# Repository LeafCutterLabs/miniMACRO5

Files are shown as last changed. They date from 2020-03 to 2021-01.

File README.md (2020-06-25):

# miniMACRO5
QMK-powered macropad based on Arduino Pro Micro. Supports a mix of up to 5 rotary encoders or mechanical switches with optional RGB underglow.
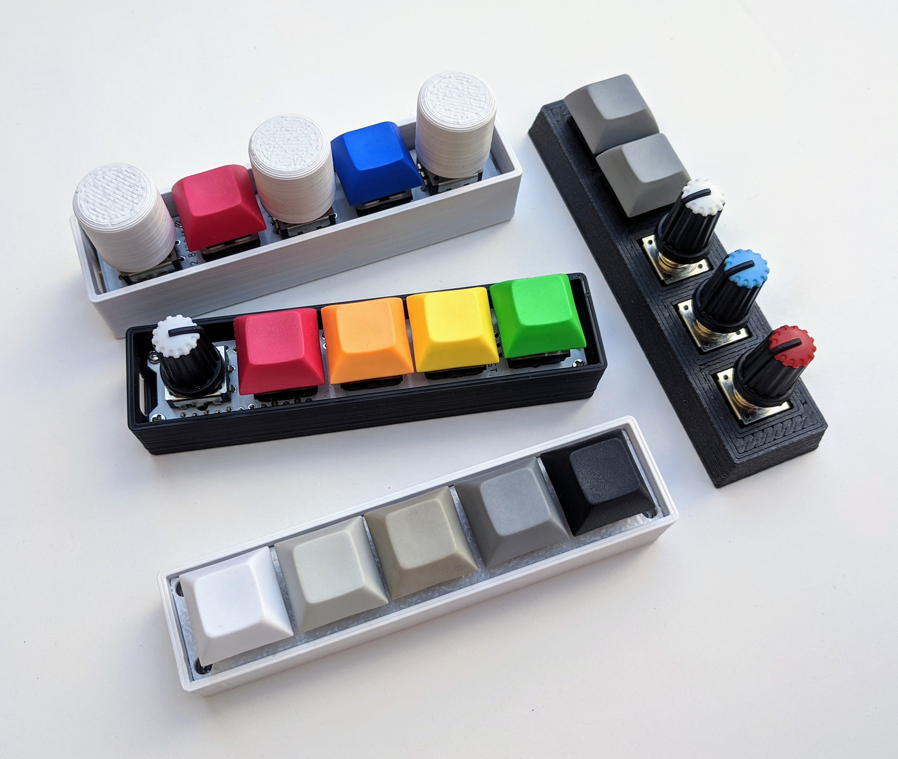
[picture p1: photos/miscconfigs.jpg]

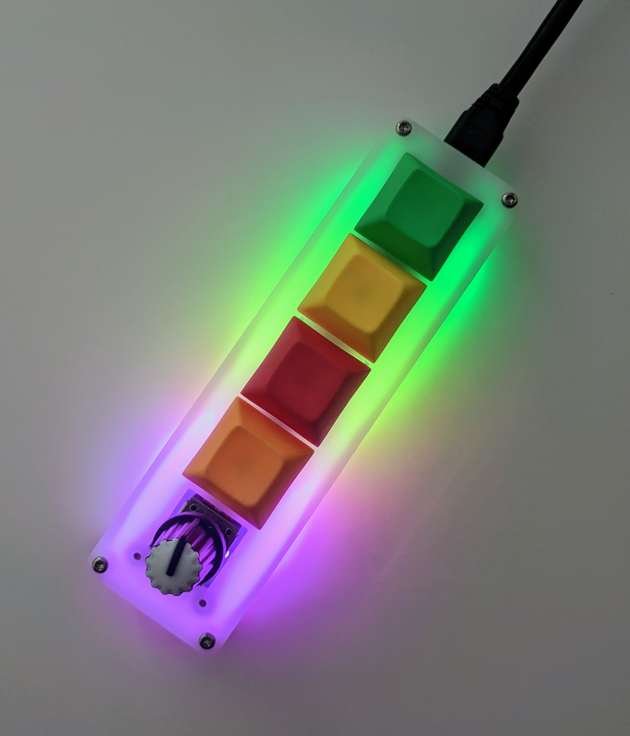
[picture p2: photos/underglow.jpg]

<br>


## Bill of materials (BOM)
### Required components
1. Arduino Pro Micro with headers - available from SparkFun, eBay, Amazon, etc.
2. Rotary encoders - Bourns PEC12R and PEC11R, Alps, and the cheap Chinese versions have been tested. Any quadrature encocder that fits should work. Supports switch encoders.
3. Cherry MX-style switches
4. Keycaps for your chosen switches
5. Case (3d printable STL in `/hardware`)
6. 4x 4mm M2 mounting screws
7. Electrical insulation tape (if you do not have any, at this low voltage and current, regular clear tape will suffice)

### Optional components
1. Reset switch
2. ICSP headers (only required to flash the Arduino if the Caterina bootloader is not present)
3. WS2812 LED strip (for RGB underglow)

## Assembly instructions
[See ASSEMBLY.md](ASSEMBLY.md) for build instructions with photos.

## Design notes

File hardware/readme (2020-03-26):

The v3/v2 stl and laser files will work with v3b boards. The new v3b case includes a top plate.

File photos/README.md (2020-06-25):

Images in this folder show the various stages of the build process.

## Assembly note
The micro USB port is very close to the pins of switch or rotary 0.  A small piece of electrical tape on top of the USB port will ensure there are no shorts.

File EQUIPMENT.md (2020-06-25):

# Equipment
This list of equipment shows what's required to build this project, as well as what is useful.  There's also a [step by step assembly guide](ASSEMBLY.md).

## Required

* Soldering iron (and stand)
* Thin solder
* Solder sucker (for removing solder in the event of mistakes)
* Computer for programming the miniMACRO5 with the QMK firmware
* Micro USB to USB A cable for connecting the miniMACRO5 to the computer

## Optional

* Helping hands (crocodile clips for holding the board, often with a magnifying glass)
* Multimeter for testing connections
* Thin nosed wire cutters / tin snips (for trimming excess header length)

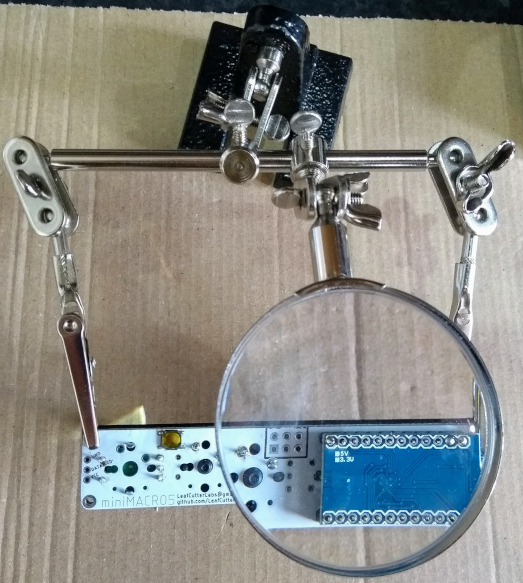
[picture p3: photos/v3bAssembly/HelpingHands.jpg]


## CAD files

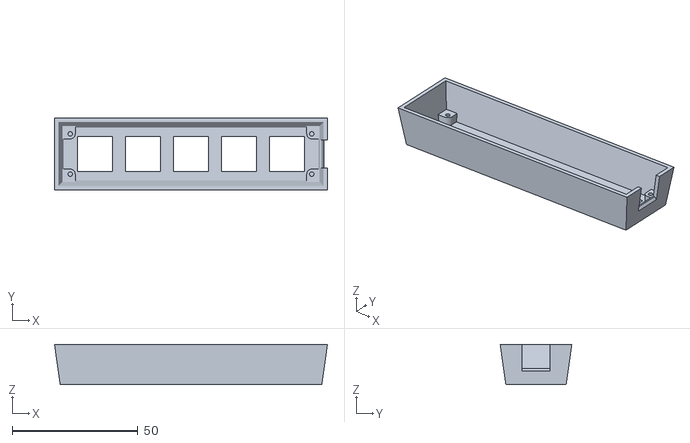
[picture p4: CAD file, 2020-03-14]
hardware/LEDunderglow.stl
108.5 x 28.5 x 16.0

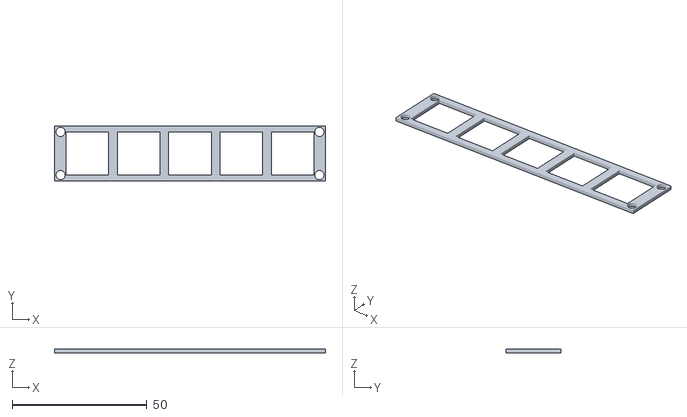
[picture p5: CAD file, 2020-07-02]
hardware/v3b/v3b - drop plate.stl
100.5 x 20.5 x 1.30

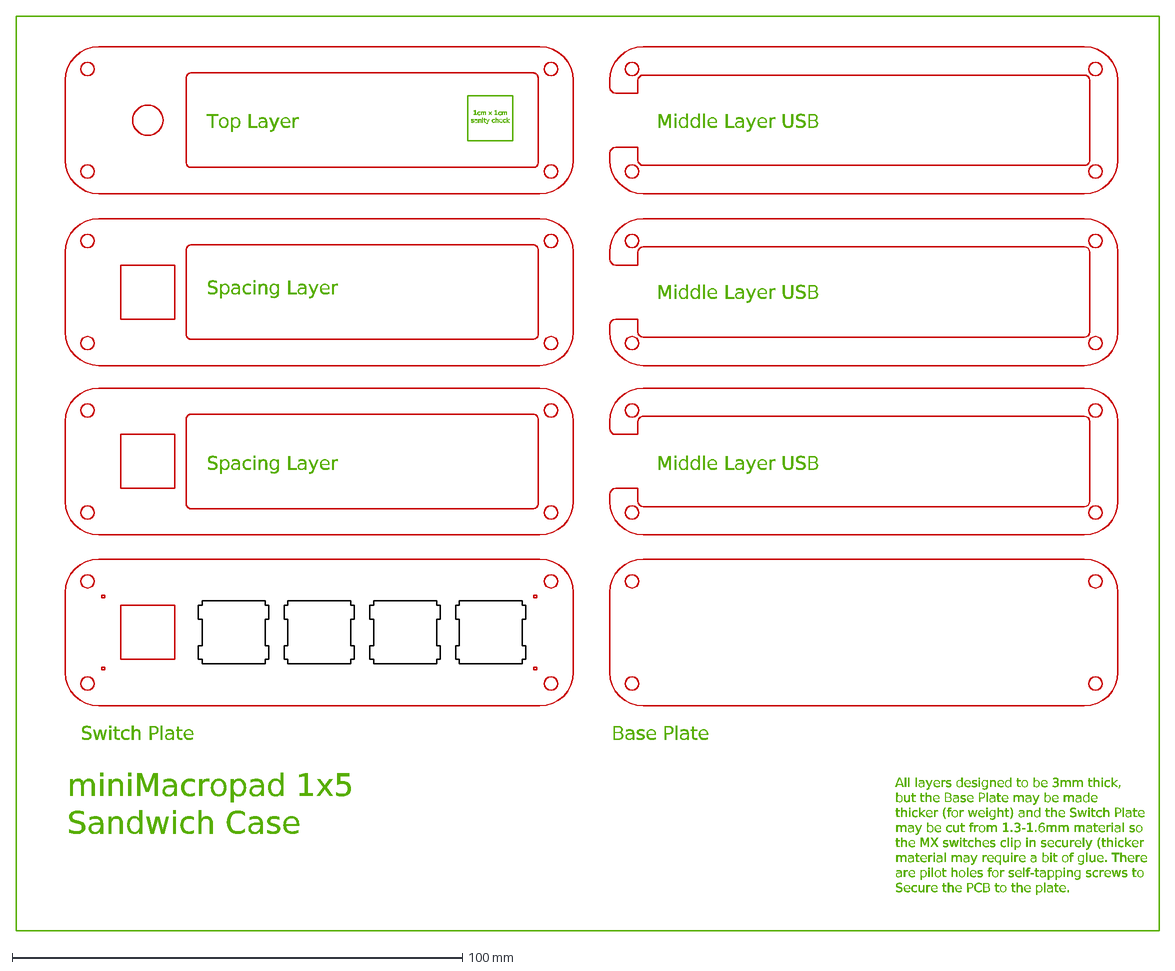
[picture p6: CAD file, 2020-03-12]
hardware/laserCUT.dxf
miniMacropad 1x5 Sandwich Case
All layers designed to be 3mm thick, but the Base Plate may be made thicker (for weight) and the Switch Plate may be cut from 1.3-1.6mm material so the MX switc
1cm x 1cm sanity check
Middle Layer USB
Spacing Layer
Top Layer
Base Plate
Switch Plate

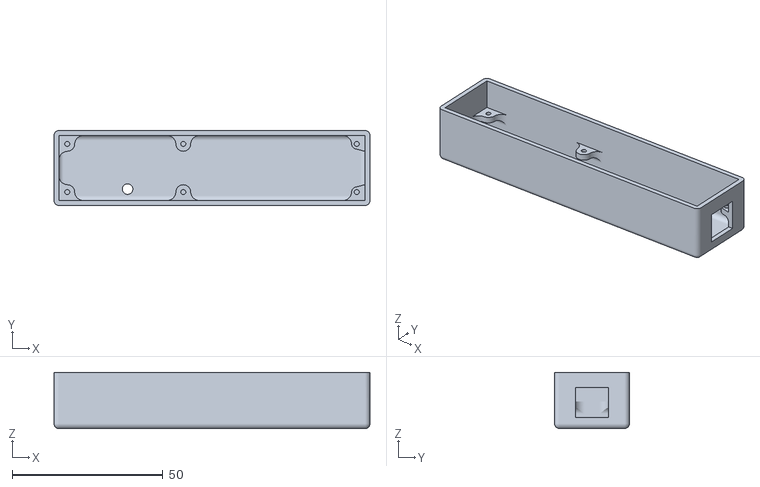
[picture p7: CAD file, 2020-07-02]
hardware/v3b/v3b - drop case.stl
104.8 x 24.8 x 18.6

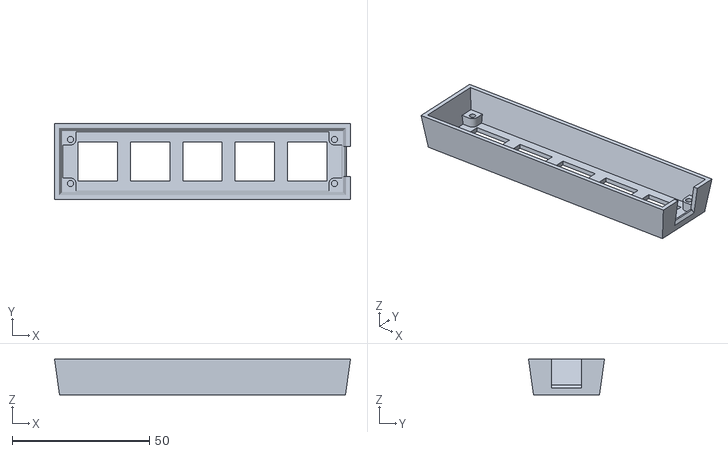
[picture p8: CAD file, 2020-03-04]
hardware/miniMACRO5.stl
107.7 x 27.7 x 13.0

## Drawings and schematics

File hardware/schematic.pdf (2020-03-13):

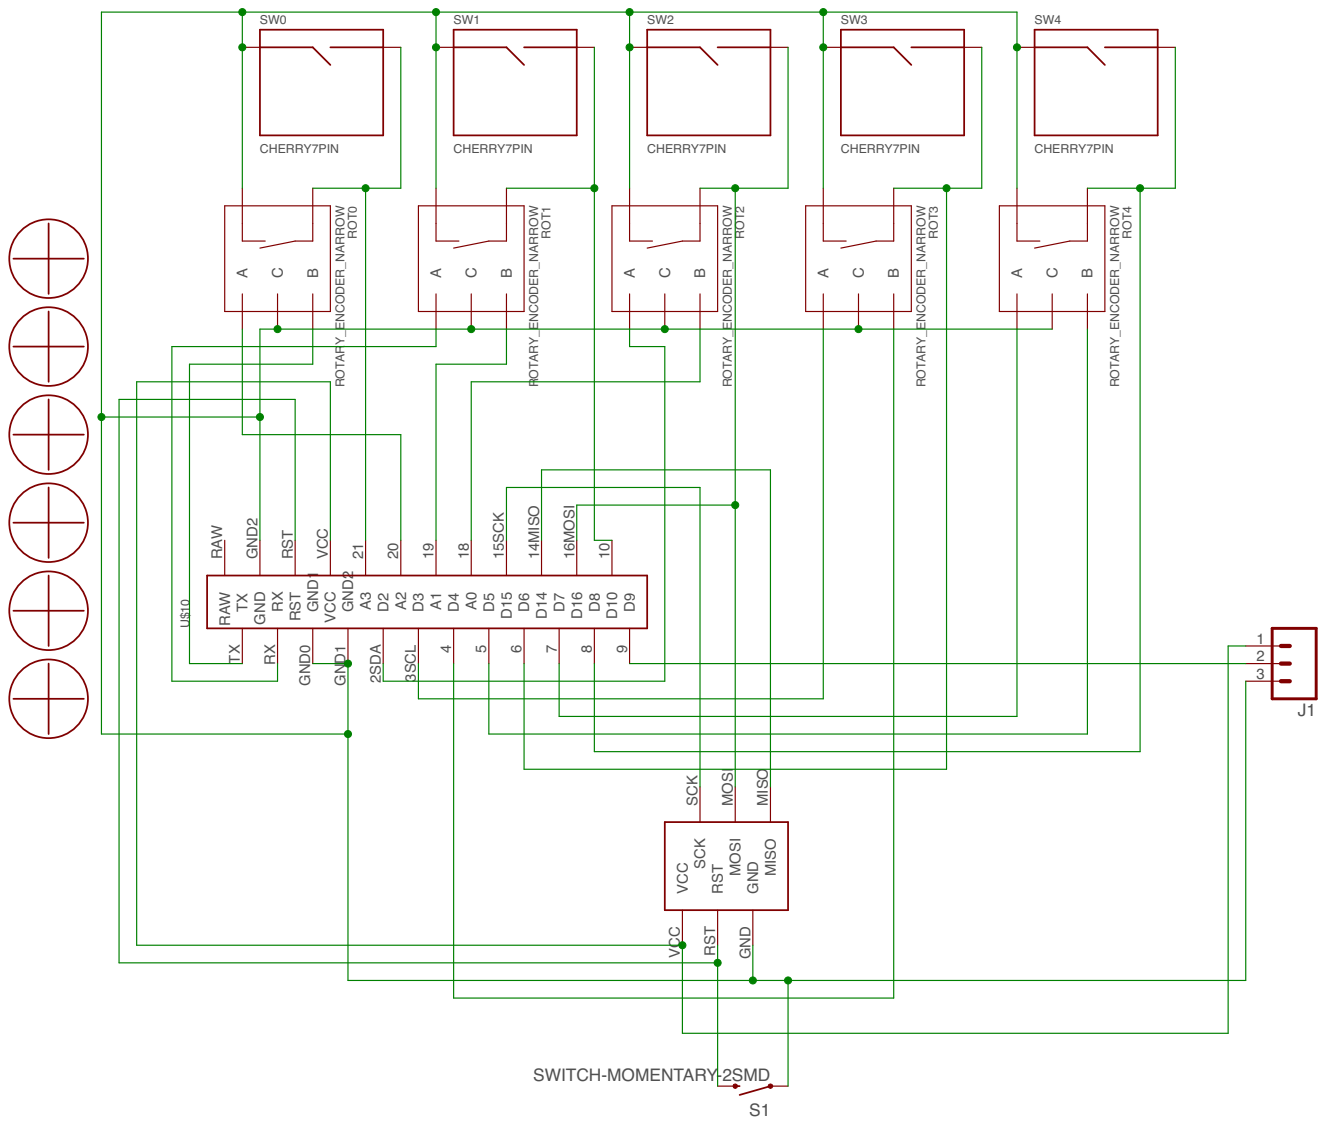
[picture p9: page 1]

RST RST GND GND2 RAW

GND GND MOSI MOSI RST RST VCC

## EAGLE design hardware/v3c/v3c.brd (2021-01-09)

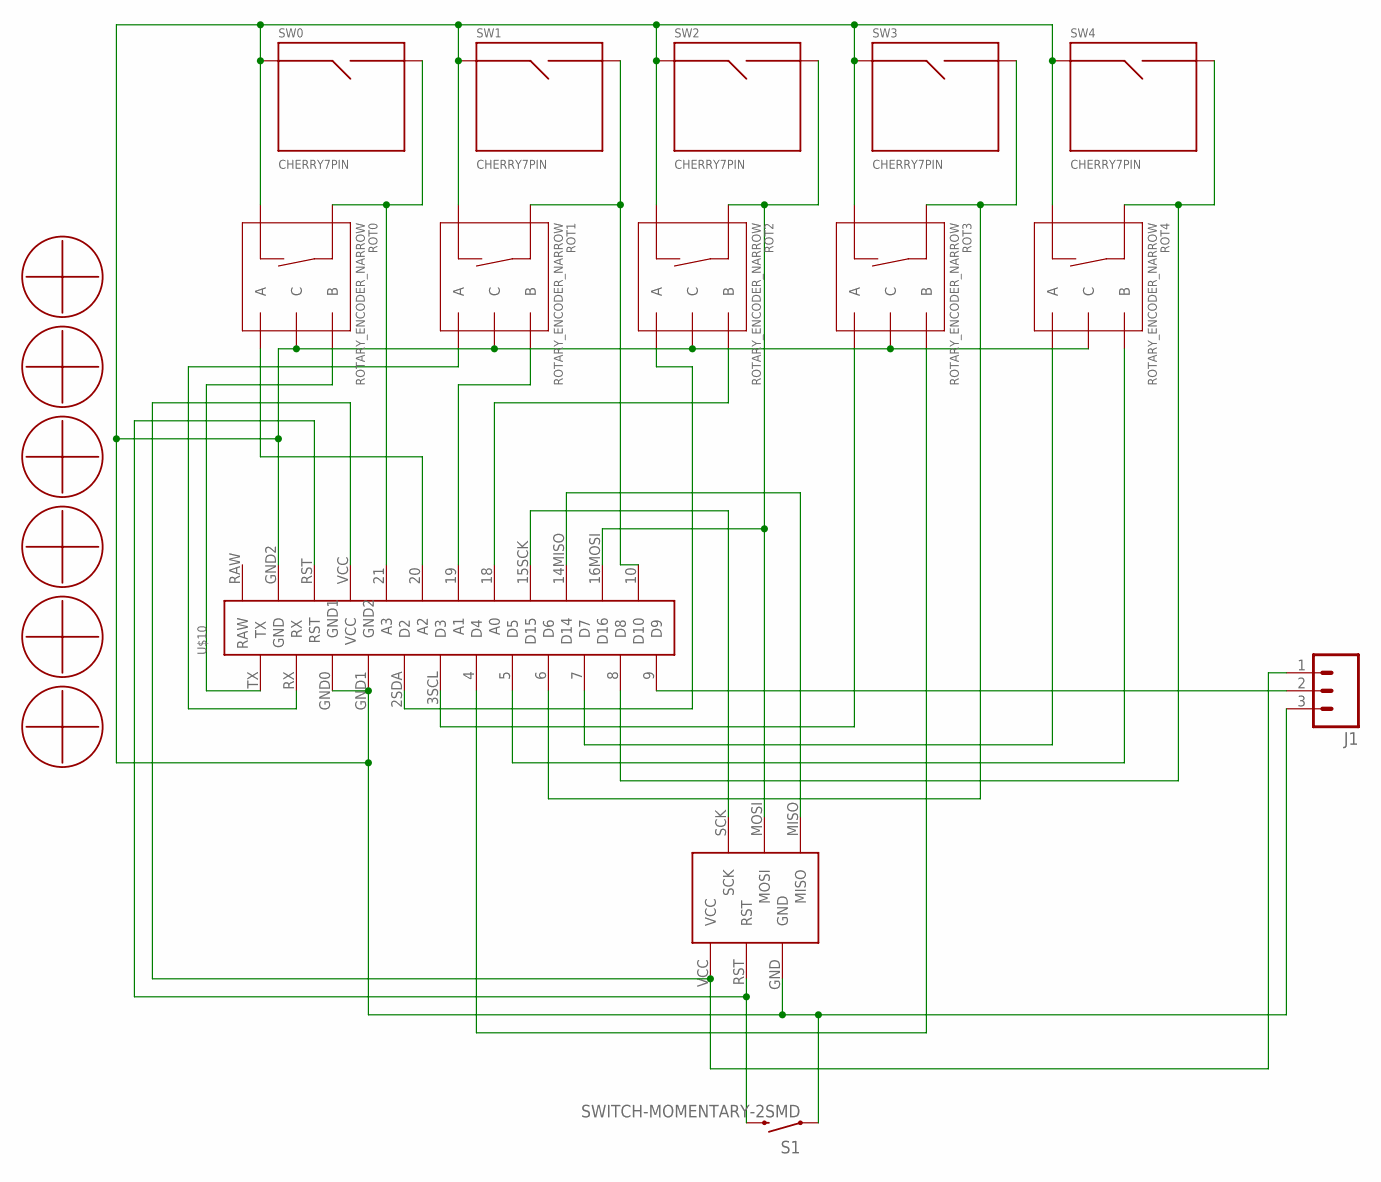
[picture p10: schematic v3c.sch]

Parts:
J1: M031X03_NO_SILK; 1X03_NO_SILK
ROT0, ROT1, ROT2, ROT3, ROT4: ROTARY_ENCODER_NARROW; ROTARY_ENC_NARROW
S1: SWITCH-MOMENTARY-2SMD; TACTILE_SWITCH_SMD
SW0, SW1, SW2, SW3, SW4: CHERRY7PIN; CHERRY5HOLE
U$1: ICSP
U$2, U$3, U$12, U$13, U$15, U$17: M2MOUNT
U$10: PROMICROLOCK; PROMICRO-LOCK

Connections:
2: ROT2.A, U$10.2SDA (D2)
3: ROT3.A, U$10.3SCL (D3)
4: ROT3.B, U$10.4 (D4)
5: ROT4.B, U$10.5 (D5)
6: ROT3.SW+, SW3.P$2 (SIG2), U$10.6 (D6)
7: ROT4.A, U$10.7 (D7)
8: ROT4.SW+, SW4.P$2 (SIG2), U$10.8 (D8)
10: ROT1.SW+, SW1.P$2 (SIG2), U$10.10 (D10)
18: ROT2.B, U$10.18 (A0)
19: ROT1.B, U$10.19 (A1)
20: ROT0.A, U$10.20 (A2)
21: ROT0.SW+, SW0.P$2 (SIG2), U$10.21 (A3)
GND: J1.3, ROT0.C, ROT0.SW-, ROT1.C, ROT1.SW-, ROT2.C, ROT2.SW-, ROT3.C, ROT3.SW-, ROT4.C, ROT4.SW-, S1.1, SW0.P$1 (SIG1), SW1.P$1 (SIG1), SW2.P$1 (SIG1), SW3.P$1 (SIG1), SW4.P$1 (SIG1), U$1.GND, U$10.GND0 (GND1), U$10.GND1 (GND2), U$10.GND2 (GND)
LEDOUT: J1.2, U$10.9 (D9)
MISO: U$1.MISO, U$10.14MISO (D14)
MOSI: ROT2.SW+, SW2.P$2 (SIG2), U$1.MOSI, U$10.16MOSI (D16)
RST: S1.3 (2), U$1.RST, U$10.RST
RX: ROT1.A, U$10.RX
SCK: U$1.SCK, U$10.15SCK (D15)
TX: ROT0.B, U$10.TX
VCC: J1.1, U$1.VCC, U$10.VCC

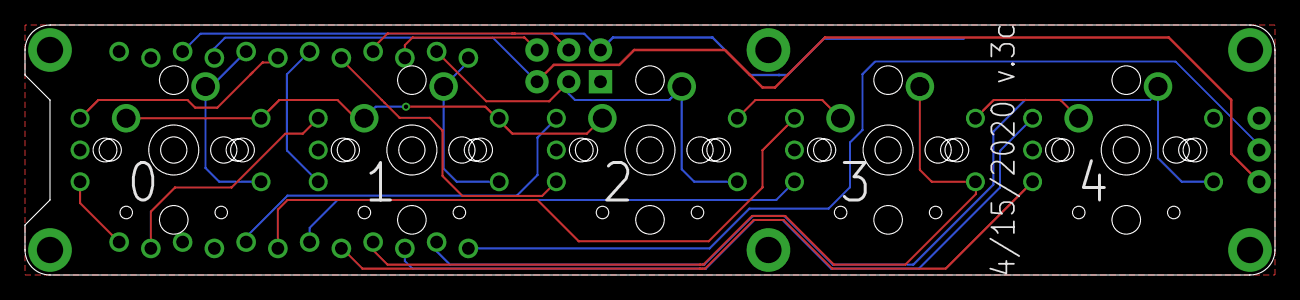
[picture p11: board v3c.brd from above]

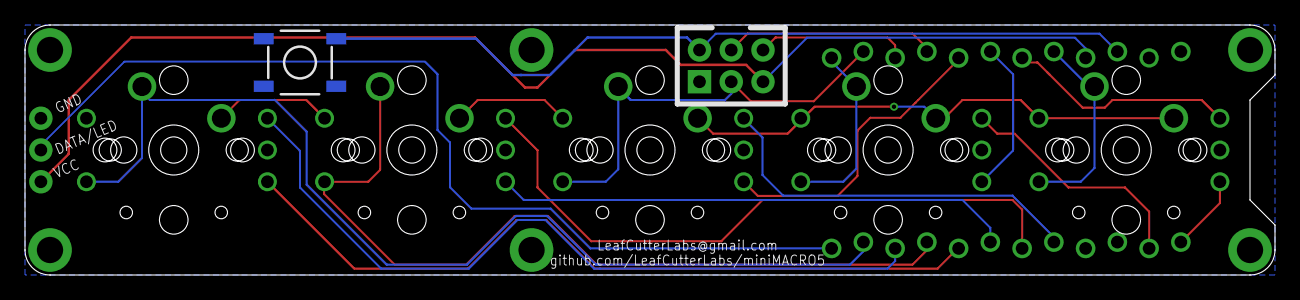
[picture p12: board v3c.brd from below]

Board: 2 copper layers, 100.0 x 20.0 mm, 20 parts (2 on the bottom side), 21 nets.

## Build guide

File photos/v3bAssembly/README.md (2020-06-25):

Images in this directory are used in the [assembly guide](../../ASSEMBLY.md).

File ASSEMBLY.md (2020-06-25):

# Assembly
Note that your components may look slightly different, or you may have chosen different components.  For a description of what the miniMACRO5 is, [see the readme](README.md) where you can also find the [bill of materials](README.md#bill-of-materials-bom).  A list of required and useful equipment can be found in [the equipment list](EQUIPMENT.md).

## A note on hardware versions
The white circuit board in these photos is a version 3b board dated 03/15/2020.  There are minor differences between the v3 and v3b board and case but these instructions should still work for the most part.

Prior to the v3b case the miniMACRO5 was installed from the underside of the case.

## Tips
### Check you have all the parts
Before you start, check you have everything you require based on the [bill of materials](README.md##bill-of-materials-bom).  Checking early avoids frustration and disappointment.

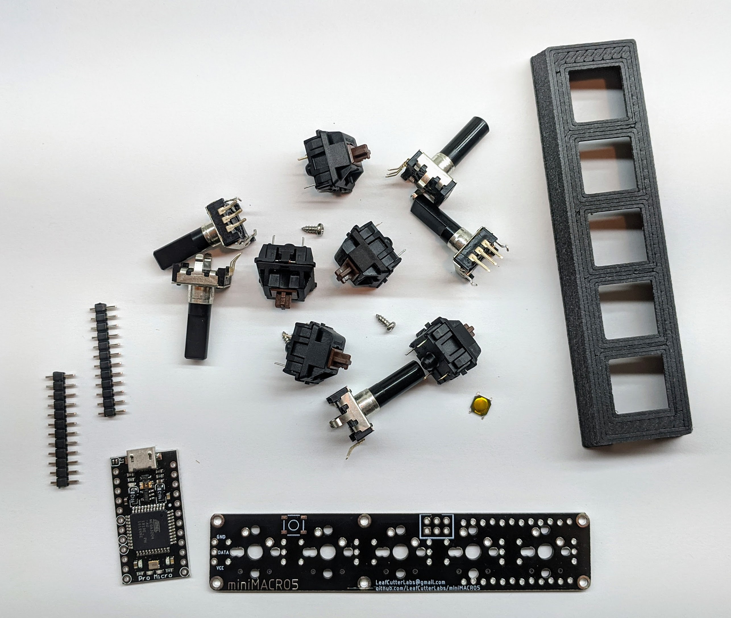
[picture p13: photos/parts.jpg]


### Solder from low profile to high profile
Where possible it's best to solder from low profile (shortest) components to high profile (tallest).  For example starting with the reset switch, then headers.

Note that if using a rotary encoder (e.g. a Bourns PEC12R or PEC11R) these must be in place _before_ the Cherry switches.  The encoder cannot be inserted from the top of the plate (the plate must be placed over the top of the encoder) due to the connections being wider than switch holes in the plate.

## Where are components mounted?
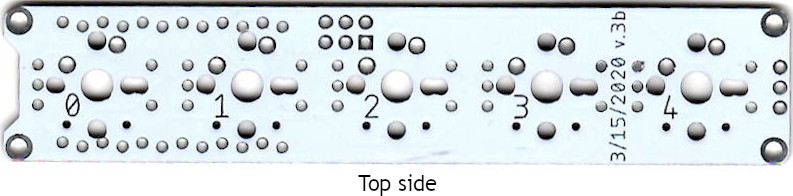
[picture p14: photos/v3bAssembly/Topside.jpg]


The _top side_ (above) of the miniMACRO5 is where the switches and encoders are mounted.  On this side of the board you'll see contacts and holes numbered 0 - 4.  Solder on the top side will be for the _ICSP header_ (optional), _MS2812b light strip_ (optional) and the _Arduino Pro Micro headers_.

The _underside_ (below), where you'll see the _miniMACRO5_ branding and the GitHub project address, is where the _ICSP header_ (optional), _reset button_ (optional) and _MS2812b light strip_ (optional) are mounted.  On the _underside_ you'll solder the encoders, switches and reset button.

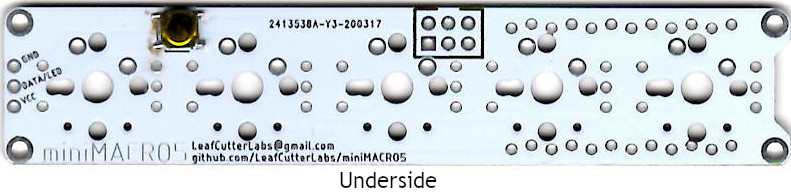
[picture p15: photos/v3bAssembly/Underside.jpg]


## Step 1 - Solder in the reset switch and ICSP ports
Solder the reset switch into place using the four pads on the underside of the board.  This is used to reboot the board in the event of problems.

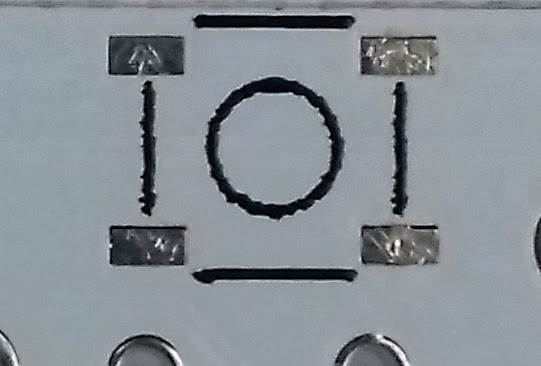
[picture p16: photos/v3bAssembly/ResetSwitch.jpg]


Next solder in the ICSP port (optional) if you need it.  The header is mounted on the underside of the board so your solder will be on the top side (where your key switches and encoder will be mounted).  There are six holes for the ICSP header, as below.

An ICSP header is only needed if the bootloader is not already installed on the Arduino Pro Micro.



## Step 2 - Solder the Pro Micro Headers onto miniMACRO5
Mount the Pro Micro headers on the _underside_ of the board, trim additional length and solder in place on the top side.

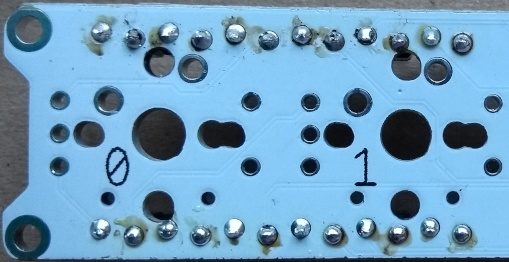
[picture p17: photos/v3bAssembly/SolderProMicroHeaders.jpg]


## Step 2a (optional) - Check for shorts
As the header has a lot of connections in a small space it it easy to create an accidental short circuit. You can check for electrical shorts by using a multimeter to test if any pins are connected together.  At this stage no pin should create a circuit with any other pin on the header.

If you find a short, remove the solder and redo the connection.

## Step 3 - Insulate the USB port
There is not much clearance between the micro USB socket and other components on the board.  Insulate the USB socket by covering it with tape (electrical insulation tape is best, although gaffa (duct tape) or selotape will also work).

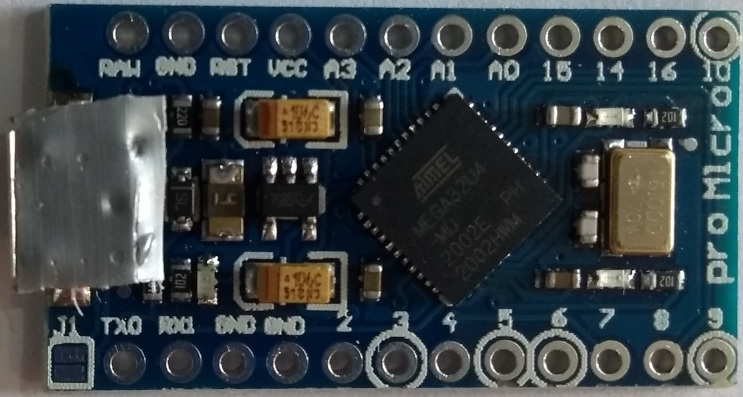
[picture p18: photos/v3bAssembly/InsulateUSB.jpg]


## Step 4 - Add and solder rotary encoders
Install rotary encoders wherever you want them (the board supports up to five). The encoders will fit through the standard 14mm square plate hole for Cherry MX style switches.  On the image below, the pink holes are for the support legs (top and bottom), the two blue holes on the right are for the encoder's push button and the three yellow holes (left) are for the rotary encoder.  Note this photo is of the top side to show you how to insert the encoder, you _must_ solder on the underside.

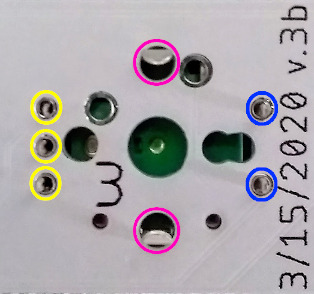
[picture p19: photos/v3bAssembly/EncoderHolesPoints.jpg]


Once mounted the encoder will look like this:

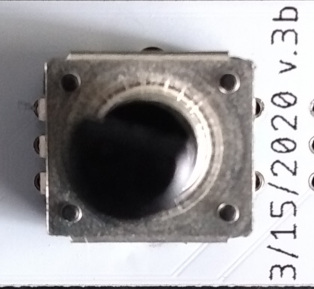
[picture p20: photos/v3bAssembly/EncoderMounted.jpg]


## Step 5 - Install switches and solder the switches
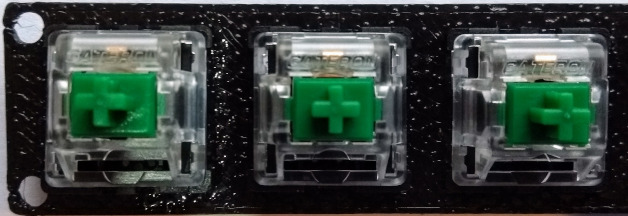
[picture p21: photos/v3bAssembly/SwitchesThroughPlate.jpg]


If using a version 3b case, press the switches into the plate until they click into place.  Then position the switches on the miniMACRO5 circuit board's _top side_.  The three pink holes (left to right) are for the stabiliser pegs while the two blue holes (above the legs) are for the copper pins.

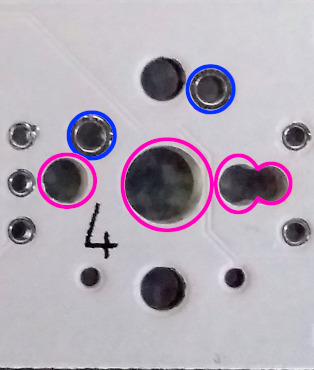
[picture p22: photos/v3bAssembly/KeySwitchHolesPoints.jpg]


Solder each of the switches to the _underside_ of the board, making contact.

Prior to the v3b case there was no plate, so the switches were first soldered to the board, then mounted into the case from the underside as below:

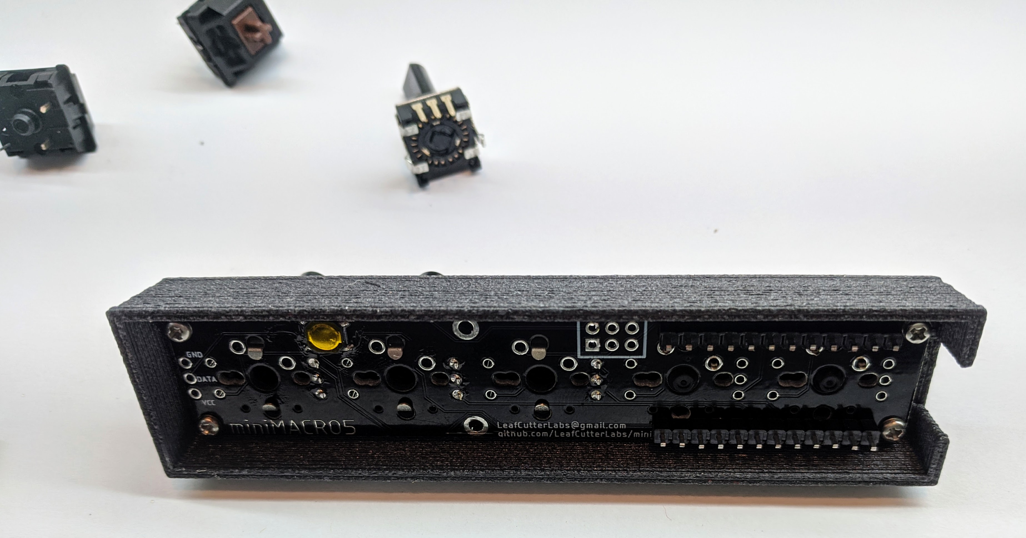
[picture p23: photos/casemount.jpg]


### A note on switches
Three and five pin Cherry MX and compatible switches (e.g. Gateron) are supported by the miniMACRO5.  A _three pin_ switch has two copper contacts and a central stabilisation peg.  _Five pin_ switches have two copper contacts, a central stabilisation peg and two side pegs.

Obviously we will only be soldering the copper contacts.

## Step 5a (optional) - Check for electrical continuity
Using a multimeter check for electrical continuity before soldering the Pro Micro into place.  There are connections under the Pro Micro and it is better to know if a repair is needed before soldering the Pro Micro into place!

## Step 6 (optional) - Solder RGB light strip
If using an RGB light strip (e.g. the MS2812b) solder that to the VCC/DATA/GND holes on the board.  The solder should be applied to the _top side_.

## Step 7 - Solder Pro Micro to Pro Micro Headers
Solder the Pro Micro to the _underside_ of the miniMACRO5 - the USB port is oriented up.  Note that if you're not using the v3b case you'll need to screw the miniMACRO5 into the case before soldering the Pro Micro in place.

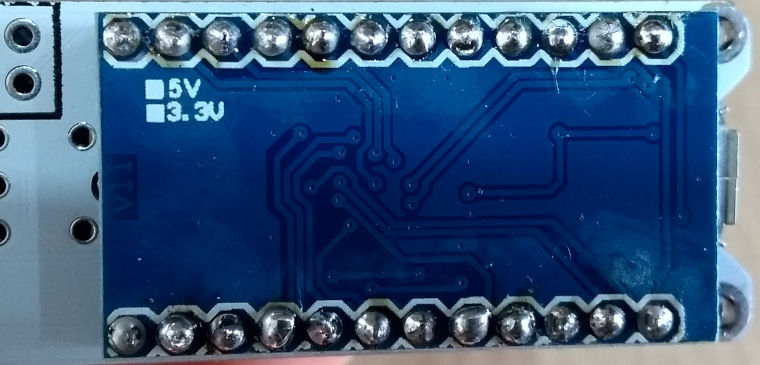
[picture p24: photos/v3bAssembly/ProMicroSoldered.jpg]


Your completed build should look similar to this:

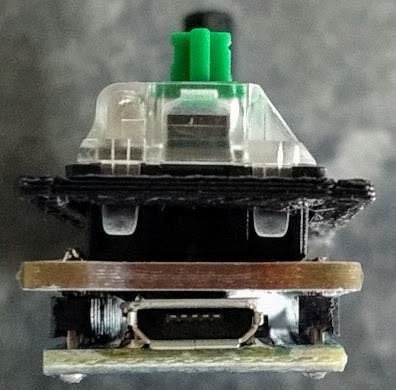
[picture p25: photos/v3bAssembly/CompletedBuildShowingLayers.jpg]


## Step 8 - Mount components into case
Lower the completed board into the v3b case.  The Arduino Pro Micro should fit between the supports (shown in pink) and the reset button should line up with the hole in the base.  Using M2 screws, secure the board into place.

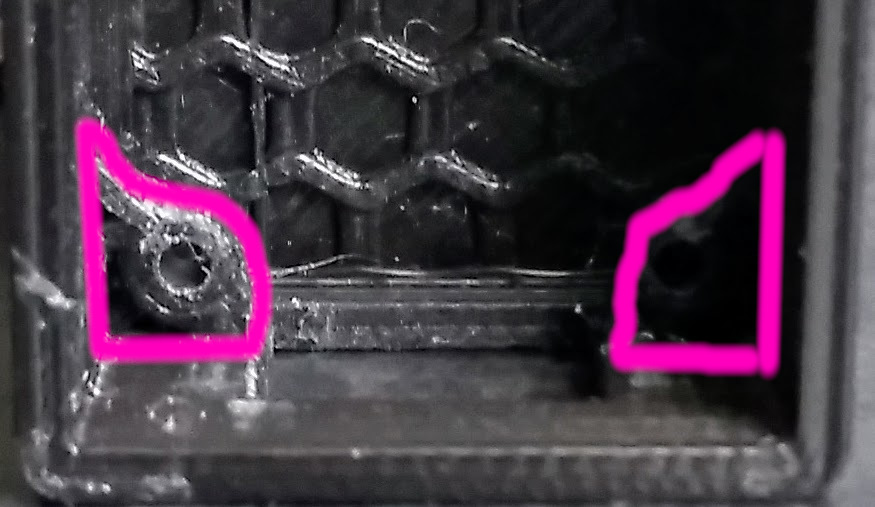
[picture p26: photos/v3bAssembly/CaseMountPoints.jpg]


Add key caps and encoder knobs as required.

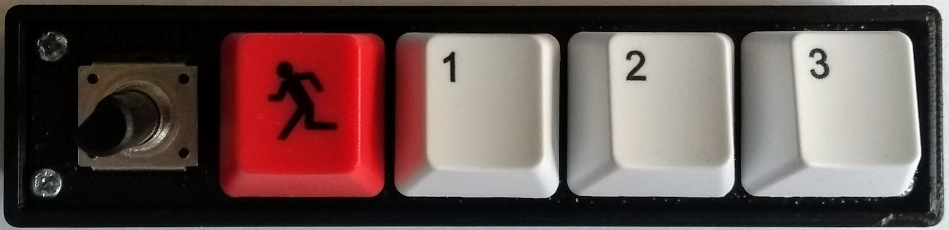
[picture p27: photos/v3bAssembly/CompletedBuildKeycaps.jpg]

	
## Step 8 - Program with QMK
The miniMACRO5 runs the [QMK firmware](https://qmk.fm/).  See files at `/firmware/QMKv3/`.

## Step 9 - Enjoy!
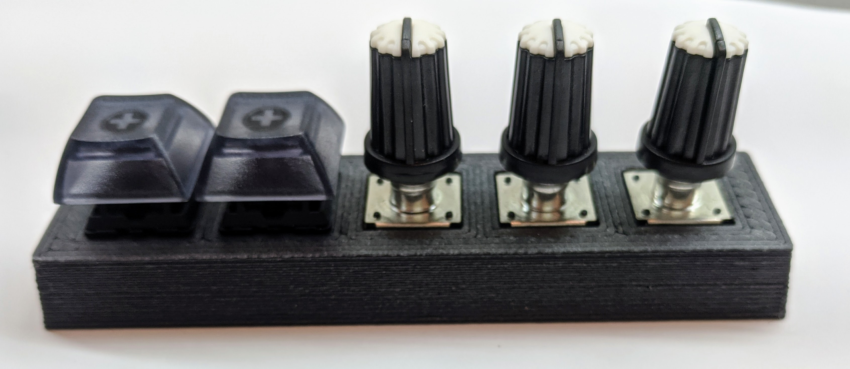
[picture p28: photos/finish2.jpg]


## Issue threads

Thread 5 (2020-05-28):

Plans to upstream?

ridingqwerty, 2020-05-28:
Hey guys, cool project!

I'm one of the QMK collaborators, and a friend of mine who had purchased the miniMACRO5 reached out to me for help flashing it.  This being his first QMK project there was probably some confusion regarding our new user documentation and interacting with projects out of tree.

That said, we were able to get it sorted (I just added all the files under QMKv3/ to my branch and gave him the hex).  I was just wondering if there were plans to get this into the main QMK repo at some point for ease of flashing?

Thanks :)

LeafCutterLabs, 2020-05-29:
Yes, I would love to have it in the main repo. How would I go about doing
that?

On Thu, May 28, 2020 at 8:14 AM ridingqwerty <notifications@github.com>
wrote:

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

ridingqwerty, 2020-05-29:
Great, that's awesome to hear!

The process is pretty straightforward -- generally you fork QMK (or if that's already done, get master updated), create a new branch, add in your changes, and then pull request to get your_fork:your_branch merged into QMK master.  Our process generally requires two collaborator approvals, but turnaround isn't too bad as long as you stay on top of any changes requested.

I'd say what you have already works pretty well -- I had no issues basically just copying everything in and building it as is.  There may need to be some minor concessions -- for example, not hosting the hardware files and having the README.md on the QMK repo be more focused on the firmware/flashing aspect -- but you could always link back to this repo from there so people would know where to find the hardware files and stuff.

I've already got a branch going on my end so if you want, I can PR it myself and tag you on it.  Let me know what you think.

meaksb, 2020-06-02:
I just bought this board and I'm having a really hard time compiling my keymap file into a HEX when attempting to make a custom layout for it. It'd be really appreciated if you could streamline this process for people like me who have limited QMK experience. I've followed chokkan's video and it's still giving me errors :(

LeafCutterLabs, 2020-06-04:
One problem is Configurator does not currently support encoders. Some problems with compiling have been case sensitivity issues. If you post your keymap I'm more than happy to compile and post it.

dezlidezlidezli, 2020-09-22:
I have recently run a group-buy for this macropad, and am working on upstreaming this code. I will update this thread with the pull request number later, I'm still working on adjusting some code slightly.

dezlidezlidezli, 2020-09-22:
https://github.com/qmk/qmk_firmware/pull/10392 alright, here is the pull request. I hope it gets merged quickly, I've done my best. Thank you @LeafCutterLabs for making this great macropad!

dezlidezlidezli, 2020-09-23:
alright, @LeafCutterLabs... we can close this issue... your firmware has been merged into QMK main

bsoll, 2020-10-03:
>
>
> alright, @LeafCutterLabs... we can close this issue... your firmware has been merged into QMK main

Awesome news! Just to clarify, it still won't support encoders for the Configurator right? What are our options for using encoders?

LeafCutterLabs, 2020-10-03:
You can always compile local for encoder support.

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

dezlidezlidezli, 2020-10-03:
Yes, unfortunately I cannot add VIA or QMK Configurator support because of the encoders. The layout appears pretty broken in the configurator, I didn’t see any use in fixing it as encoders wouldn’t work anyway. Once better encoder support is released, I will happily update QMK main.

To program encoder functions yourself, you would do it in the same way as you would have previously with using files from this repository, but you won't need to work with extra remotes and it is part of the default QMK release. Customising the functions of this macro-pad (encoder or not) would mean editing it as if it was any other QMK file.

The default key-map has placeholder key codes, for ease of customisation and to reduce confusion to those new to working with encoders or new to QMK. You can see the accompanying image [here](https://imgur.com/a/uPHNHCn), which will feature in a step by step key-map customisation guide specific to the miniMACRO5 guide which I am currently writing.

The media key-map is basically the same as the one provided here in this repository. There were some changes made to the QMK firmware, to fit in with more modern practices recommended by the contributors to that repository. Notably, I have removed the RGB tap-dance parts of the software as I believe they were superfluous and something that can be added back later. I am soon going to be adding many custom user keycaps for members of my group-buy, where I will add back a clean default key-map copied right from this repository.

I have put quite a lot of effort into documenting and improving the situation for this macro-pad since I have run a group-buy for it, I plan to offer some pull requests to this repository with improved documentation and hardware files. For example, I have redesigned the plate since the switch holes were the wrong size, I have access to V3c Gerber files sent to me by LeafCutterLabs and I have many other notes to add into documentation about how to program, build and manufacture this macro-pad. I am eager to share my improvements and findings with the public, when I get some time.

If you think of a better solution for customisation, please let me know. I'm eager to work on bringing VIA or QMK Configurator support for this macro-pad once the support is there. Thank you!

PLEASE NOTE THAT I DO NOT HAVE PCBs IN HAND YET, I CAN SEE NO REASON IT WOULDN'T, BUT THE FIRMWARE UPSTREAM MAY NOT WORK. I WILL FIX THIS AND TEST THIS WHEN MY PCBs ARRIVE IN ABOUT 2 WEEKS.

joncojonathan, 2020-10-09:
@dezlidezlidezli thanks for doing that.  It was on my list of things to do but then life happened and I've not been able to return to it.  I'll take a look at your QMK PR so I can see how to do the same for the other boards by @LeafCutterLabs.

Thanks for your contribution :) .

Closed 2020-11-09.

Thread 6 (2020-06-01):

Gerber files for v3b board required

joncojonathan, 2020-06-01:
It would appear the v3b board Gerber files are missing from the repo.  [This file](https://github.com/joncojonathan/miniMACRO5/blob/master/hardware/v3gerber.zip) is for the v3 board (dated 2020-02-16), however, the current boards being sold appear to be a later revision, v3b (dated 2020-03-15).

Please could the v3b Gerber files be uploaded, potentially deprecating the older file?  I note on the v3 PCB layout the pins are in a slightly different location.  It appears the drill scaling may also be off (I'm not familiar with making PCBs, a friend had to explain).

Many thanks for all your work on this @LeafCutterLabs.

mariemat, 2020-06-02:
I've seen this too. Layers from V3 PCB are not aligned correctly, it seems.
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

LeafCutterLabs, 2020-06-04:
Uploaded the v3b board. The holes line up but there is a difference between the plated holes and regular drills. The non-plated holes are for the encoder mechanical attachment and 5th holes on the Cherry MX footprint.

joncojonathan, 2020-06-07:
Many thanks @LeafCutterLabs .

Closed 2020-06-07.

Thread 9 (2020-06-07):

hardware/v3b/v3b-plate.stl actually the case

joncojonathan, 2020-06-07:
Thanks for the v3b case files at `hardware/v3b/`.  I've noticed the plate (`v3b-plate.stl`) is actually another copy of the case, and `md5sum` shows they're the same file but with different names.

Please could you provide the plate for v3b?  Many thanks.

```md5sum
0ece18a04be3ff5536e263b6578191e7  v3b-case.stl
0ece18a04be3ff5536e263b6578191e7  v3b-plate.stl
```

joncojonathan, 2020-06-28:
Edited issue to correct a typo.  The two STL files are both the case, so the plate is missing.

LeafCutterLabs, 2020-07-02:
Corrected

Closed 2020-07-02.

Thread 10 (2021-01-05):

Gerbers for v0.3c ?

chechu2k5, 2021-01-05:
Hi!

First off, many thanks for making this amazing PCB!
I had purchased a set of these PCBs from your Tindie store and had received the boards with the date 04/15/2020 v.3c printed on the silkscreen. I was looking for the corresponding gerber files in this repo but only found the ones for v3(indvidual) and v3b (panelized). Any chance you could upload the ones for the version I have ?

I think it would be immensely useful if you could tag specific commits as releases and/or populate a CHANGES file to let others know what's changed, fixed or improved. I am curious if there are any specific issues with the v3 and v3b that are fixed in v3c ?

Thanks

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

LeafCutterLabs, 2021-01-09:
Thank you for pointing it out to me and I really need to improve my documentation. I can't really remember from 9 months ago but I think just the mounting holes in the middle were added. I just added the newest gerber/eagle files and will have a change log going forward.

Closed 2021-01-09.

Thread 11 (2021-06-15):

slicer settings for drop plate

mousemat86, 2021-06-15:
Thanks for sharing this project.

What slicer settings are you using for the plate? I'm getting missing sections around the holes using a 0.4mm nozzle

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

georgerappel, 2023-02-21:
I tried to print it using 3D through JLCPCB and got the same issue, asking to increase the size on the corners to at least 0.8mm around the holes.
I noticed the main case doesn't have this issue, with each pin having a bigger section around it. Maybe someone with more experience could do some customization, but I can't imagine how it would work since you either have the plate fitting the box/screws or you don't haha

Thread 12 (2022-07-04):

BOM missing part number for reset switch

JellyTitan, 2022-07-04:
The BOM has no part number for the reset switch. Do you happen to have a digikey part number for it?

LeafCutterLabs, 2022-07-05:
Not sure on digikey but most 5.1 smd switches should work:
https://lcsc.com/product-detail/Tactile-Switches_XKB-Connectivity-TS-1187A-B-A-B_C318884.html

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

JellyTitan, 2022-07-07:
Thanks for the update! I'll put in a pull request with an updated BOM, and a note about jumping to flash.

Closed 2022-07-07.

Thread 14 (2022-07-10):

Two ground pins should or should not short?

JellyTitan, 2022-07-10:
Step 2a states that no two pins should short after soldering on the pro micro headers. Testing the board before the headers are attached, it looks like the two GND pins next to each other short. Is this working as intended?

georgerappelmeliuz, 2023-03-21:
That is indeed correct. The third and fourth pin on one side should be shorted when measuring with a multimeter. And each of them should in turn short with the second pin (also GND) on the opposite side.

Closed 2023-03-27.

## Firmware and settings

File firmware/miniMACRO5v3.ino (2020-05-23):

/* 8/30/19 PCB PINOUTS
 *USB (Button closest to USB is first)        A3 14 15 10 16 
 *A/B/Button [0,1,NC][2,3,8][7,9,6] I did not wire in the switch for the rotary closest to usb, will be fixed in future revisions.
 */

#include "Keyboard.h"
#include <SimpleRotary.h>

SimpleRotary rotaryA(20,1,21); // Pin A, Pin B, Button Pin
SimpleRotary rotaryB(0,19,10); // Pin A, Pin B, Button Pin
SimpleRotary rotaryC(2,18,16); // Pin A, Pin B, Button Pin
SimpleRotary rotaryD(3,4,6); // Pin A, Pin B, Button Pin
SimpleRotary rotaryE(7,5,8); // Pin A, Pin B, Button Pin

byte buttonPin[]={21, 10, 16, 6, 8};
char buttonVal[]={'q','f','e','n','t'};
bool buttonState[]={0, 0, 0, 0, 0};
int rotVal[3][2][3]={
  {{122,0,0},{129,122,0}}, //z and shift+z
  {{129,218,0},{129,217,0}}, //shift Left Right arrows for panning
  {{129,216,0},{129,215,0}} //shift Up Down arrows for panning
  {{122,0,0},{129,122,0}}, //z and shift+z
  {{129,218,0},{129,217,0}}, //shift Left Right arrows for panning
};

void setup() {
  Keyboard.begin();
  
  for (int i = 0; i < 5; i++){
    pinMode(buttonPin[i], INPUT);
    digitalWrite(buttonPin[i], HIGH); //turn on pull-up resistor
  }
}

void loop() {
  byte rotA, rotB, rotC, rotD, rotE;

  // 0 = not turning, 1 = CW, 2 = CCW
  rotA = rotaryA.rotate();
  rotB = rotaryB.rotate();
  rotC = rotaryC.rotate();
  rotD = rotaryD.rotate();
  rotE = rotaryE.rotate();

  if(rotA!=0) kPress(0,rotA-1);
  if(rotB!=0) kPress(1,rotB-1);
  if(rotC!=0) kPress(2,rotC-1);
  if(rotD!=0) kPress(0,rotD-1);
  if(rotE!=0) kPress(1,rotE-1);

  if ((digitalRead(buttonPin[0]) != buttonState[0])||(digitalRead(buttonPin[1]) != buttonState[1])||(digitalRead(buttonPin[2]) != buttonState[2])||(digitalRead(buttonPin[3]) != buttonState[3])||(digitalRead(buttonPin[4]) != buttonState[4])){
    delay(5); //debounce delay, see if its a true reading
    
    for (int i = 0; i < 5; i++){
      if ((digitalRead(buttonPin[i])!=buttonState[i])){
        buttonState[i] = digitalRead(buttonPin[i]);
        if(!buttonState[i]) Keyboard.write(buttonVal[i]);
      }
    }
  }
}

void kPress (byte encoder, bool cw){ //encoder and clockwise?
  for (int i=0; i<5; i++) Keyboard.press(rotVal[encoder][cw][i]);
  Keyboard.releaseAll();
}

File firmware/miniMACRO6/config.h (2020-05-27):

/*
Copyright 2012 Jun Wako <wakojun@gmail.com>

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
You should have received a copy of the GNU General Public License
along with this program.  If not, see <http://www.gnu.org/licenses/>.
*/

#pragma once

#include "config_common.h"

/* USB Device descriptor parameter */
#define VENDOR_ID       0xCEEB
#define PRODUCT_ID      0x0007
#define DEVICE_VER      0x0001
#define MANUFACTURER    leafcutterlabs
#define PRODUCT         miniMACRO6
#define DESCRIPTION     6 key/rotary  board

/* key matrix size */
#define MATRIX_ROWS 1
#define MATRIX_COLS 6

/*
 * Keyboard Matrix Assignments
 *
 * Change this to how you wired your keyboard
 * COLS: AVR pins used for columns, left to right
 * ROWS: AVR pins used for rows, top to bottom
 * DIODE_DIRECTION: COL2ROW = COL = Anode (+), ROW = Cathode (-, marked on diode)
 *                  ROW2COL = ROW = Anode (+), COL = Cathode (-, marked on diode)
 *                  NO_DIODE = switches are directly connected to AVR pins
 *
*/
// #define MATRIX_ROW_PINS { D0, D5 }
// #define MATRIX_COL_PINS { F1, F0, B0 }
#define DIRECT_PINS {   \
    { D4, F4, F5, C6, B4, B6 } \
}
//speed for double tap
#define TAPPING_TERM 200

#define UNUSED_PINS

/* rotary encoder 0 on the left 1 on the right*/ 
#define ENCODERS_PAD_B { D2, E6}
#define ENCODERS_PAD_A { D3, D0}
#define ENCODER_RESOLUTION 2 //default/suggested

/* ws2812 RGB LED */
#define RGB_DI_PIN B5
#define RGBLIGHT_ANIMATIONS
#define RGBLED_NUM 4    // Number of LEDs

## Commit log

2020-04-12 Updated BOM for clarity
2020-05-12 Add files via upload
    fixed A and B encoder pads so Clockwise and Counter Clockwise worked correctly in the keymaps
    [config.h]
2020-05-23 New V3 sketch
    Not tested and does not support LED underglow (arduino pin 9)
2020-06-02 Fix typo, move and link assembly instructions
2020-06-02 Begin adding assembly instructions
2020-06-02 Re-order assembly instructions, add tips
2020-06-02 Add tape to the bill of materials
2020-06-04 v3b gerber
2020-06-07 Add photo (switches in plate)
2020-06-07 Add mounting description and photos
2020-06-07 Add encoder photo and instruction
2020-06-07 Add switch pin out and instructions
2020-06-07 Add Pro Micro soldering instructions
2020-06-07 Add mount instructions
2021-01-09 added v3c gerber/eagle files
    [v3c.brd, v3c.sch]

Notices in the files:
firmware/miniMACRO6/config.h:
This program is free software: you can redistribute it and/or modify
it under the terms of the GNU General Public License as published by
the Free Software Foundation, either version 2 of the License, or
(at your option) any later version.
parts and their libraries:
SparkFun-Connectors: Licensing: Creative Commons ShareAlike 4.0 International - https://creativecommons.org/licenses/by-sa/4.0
